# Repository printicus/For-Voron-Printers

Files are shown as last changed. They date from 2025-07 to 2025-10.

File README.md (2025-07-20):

# For Voron Printers
Parts, modded parts and accessories for Voron Printers

These are a ME project. I designet, remixed or modded these files for me, but I uploaded them here, maybe someone will find them interesting and will want to use them. I use Super Slicer as my slicer of choice, wich has an option for "Vertical Hole shrinking compensation" that allows me to tune vertical holes diameter without modifying other dimensions. This will make the vertical holes a bit smaller when my files are used with other slicers, especially for screw holes ment for selftapping. Be aware of that, or parts will break!

I included a file for vertical hole tuning if you want to do that.

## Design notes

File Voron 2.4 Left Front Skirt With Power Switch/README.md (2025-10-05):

# Voron 2.4 Left Front Skirt With Power Switch

Much easier to power on and off the printer. Can be used as a emergency switch. I dont know if it fits a Trident, I did not check.

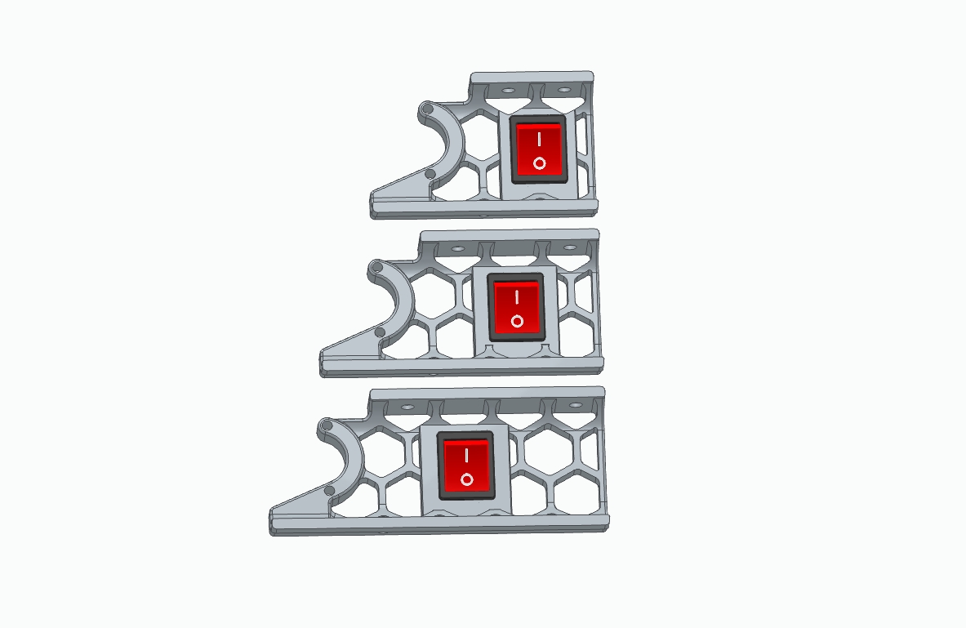
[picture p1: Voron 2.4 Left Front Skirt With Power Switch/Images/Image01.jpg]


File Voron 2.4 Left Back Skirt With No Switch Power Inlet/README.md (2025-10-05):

# Voron 2.4 Left Back Skirt With No Switch Power Inlet

If you have a front power switch on your Voron 2.4, maybe you will need this.

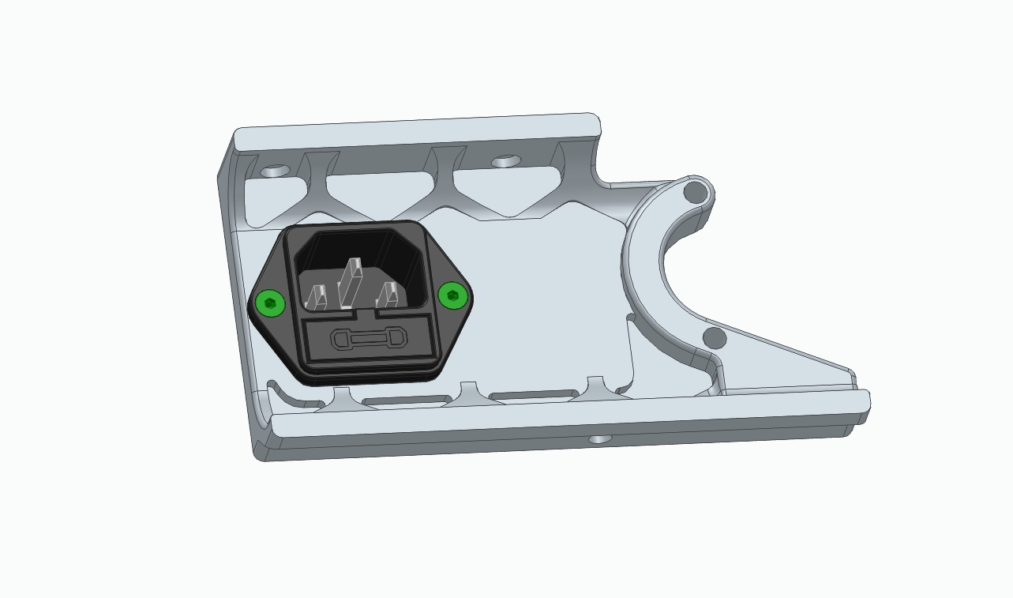
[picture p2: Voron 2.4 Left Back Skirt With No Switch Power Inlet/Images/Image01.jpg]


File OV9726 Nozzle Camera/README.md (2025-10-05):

# Nozzle Camera for Toolchanger XY Nozzle Calibration

Camera setup for XY nozzle calibration in toolchanger setups. Can be use for that with [Axiscope]( https://github.com/nic335/Axiscope ) or any other softare. Or it can be used as a simple webcam on your computer.

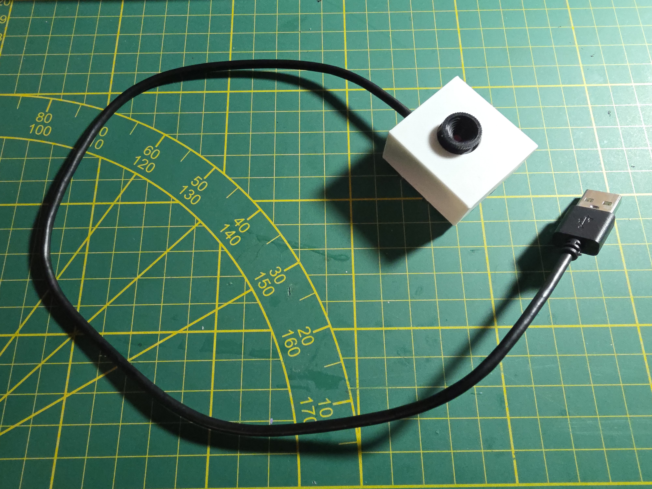
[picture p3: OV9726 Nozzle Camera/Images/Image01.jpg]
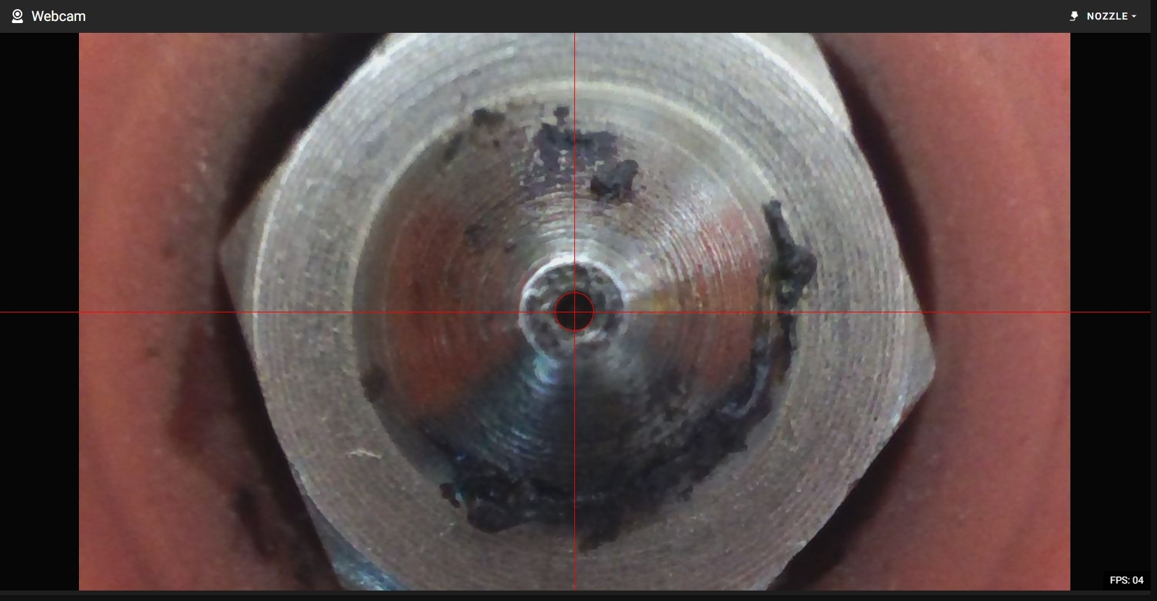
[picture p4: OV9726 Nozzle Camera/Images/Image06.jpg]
  

## BOM:
- Filament whatever type you want
- M3 Heat Insert x4
- M3x10 Socket Head(can be M3x12) x4
- OV9726 Camera Module(or similar) [Aliexpress]( https://www.aliexpress.com/item/1005003808666298.html )
- 6x3x2 N52 Magnets x8
- M2x6 Countersunk Self Tapping Screw x8

Alternative to magnets you can simply use double sided tape.

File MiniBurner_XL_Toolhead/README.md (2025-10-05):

## MiniBurner XL Toolhead

This are the files for Miniburner XL Toolhead.

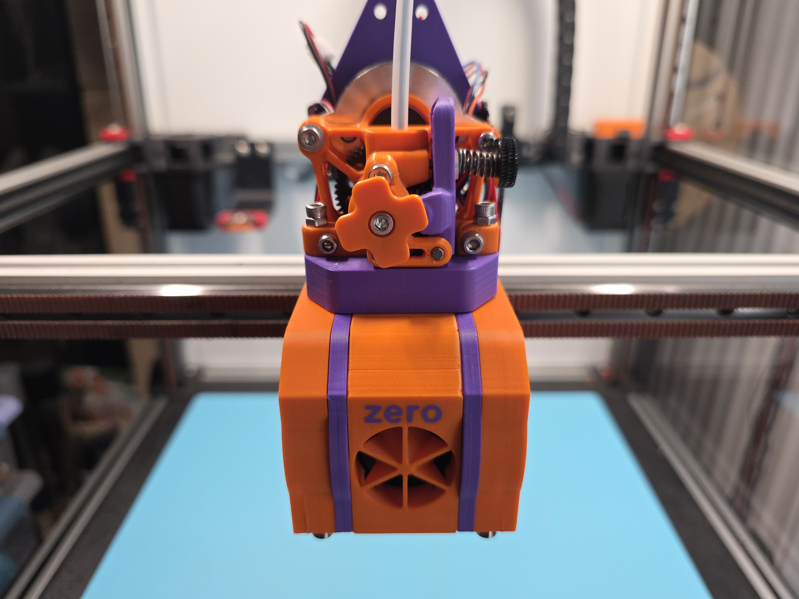
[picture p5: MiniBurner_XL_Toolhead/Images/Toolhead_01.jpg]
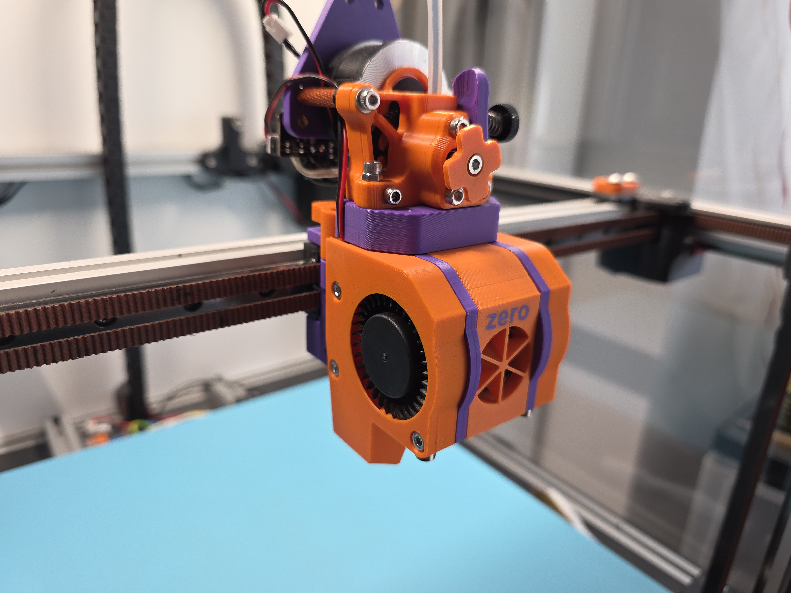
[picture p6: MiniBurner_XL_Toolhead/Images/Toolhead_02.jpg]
  

Its build for hotends with volcano lenght nozzle, has a 2510 hotend cooling fan, and dual 5015 "rehoused" part cooling fans.
For now only 3 hotend are suported, and extruder suport are for sherpa-mini and Orbiter v2 - v2.5.

I designet this toolhead to be compatible with the original Voron X-Carriage, and for [Klicky-Changer](https://github.com/printicus/Klicky-Changer)

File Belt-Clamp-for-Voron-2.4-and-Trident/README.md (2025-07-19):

# Belt Clamp for Voron 2.4 an Trident
 Belt Clamp

Adjustable X-Y Belt Clamp for 6 and 9mm belts, for use with Voron 2.4 and Trident. It can be adjusted so that it will remove the belt tension between the clamps so that you can mount or change the shuttle. It can be used allso for pretensioning new belts.

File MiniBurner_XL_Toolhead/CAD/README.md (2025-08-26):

## MiniBurner XL Toolhead

CAD files for my toolhead Miniburner XL.

An Atempt for an assembly tutorial:

Assembly Tutorial (https://youtu.be/ew-SoRTqHR0)  Fan Prepping (https://youtu.be/SxsvMOHyB7k)

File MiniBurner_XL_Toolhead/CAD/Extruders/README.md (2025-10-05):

## Bom for Extruder Suports:
- Filament: ABS or ASA
- Heat Inserts(voron specs) x2
- M3x20 x2 Cap Screws for securing the extruder support on the toolhead
  - For Sherpa Mini:
    - M3x18  x2 Cap Screws - for securing the extruder on the extruder support
    - M3x25  x2 Cap Screws - for securing the extruder on the extruder support with the filament cutter addon
  - For Orbiter v2
    - M3x14  x2 Cap Screws - for securing the extruder on the extruder support
    - M3x20  x2 Cap Screws - for securing the extruder on the extruder support with the filament cutter addon

## Toolboards Supports

You can use the toolboarts supports that I providet here or you can use whatever toolboards supports you can find online that apply to the Sherpa Mini and Orbiterv2
## BOM:
- Filament: ABS or ASA
- Heat Insert(voron specs) x2
- M3x8  x2 for securing the toolboard support on the extruder
- M3x10  x2 for securing the toolboard
- Spacer  x2 between the extruder and extruder support. the lenght for this spacers depends on what size(length) motors you have. I prefer metalic ones.

## Links:
- Spacers - https://de.aliexpress.com/item/1005006251587333.html - or - https://de.aliexpress.com/item/1005003493226449.html

# Filament Cutter Addon

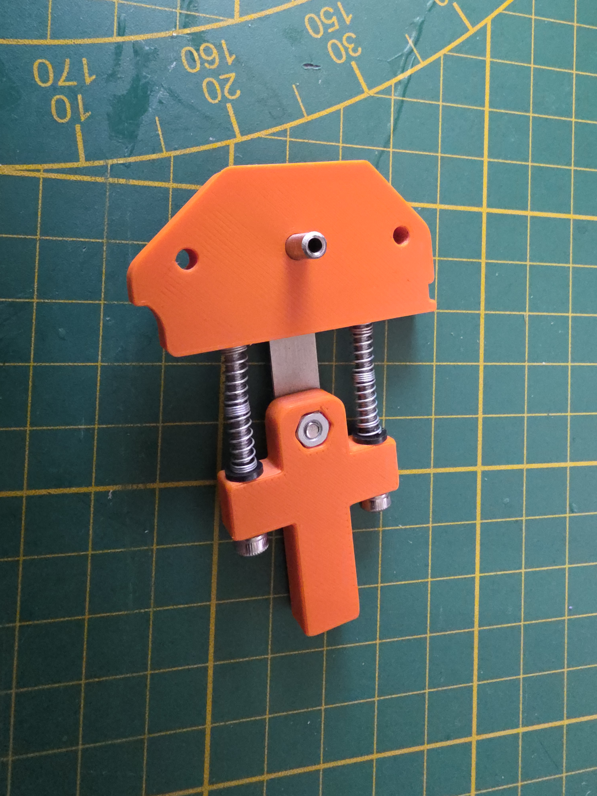
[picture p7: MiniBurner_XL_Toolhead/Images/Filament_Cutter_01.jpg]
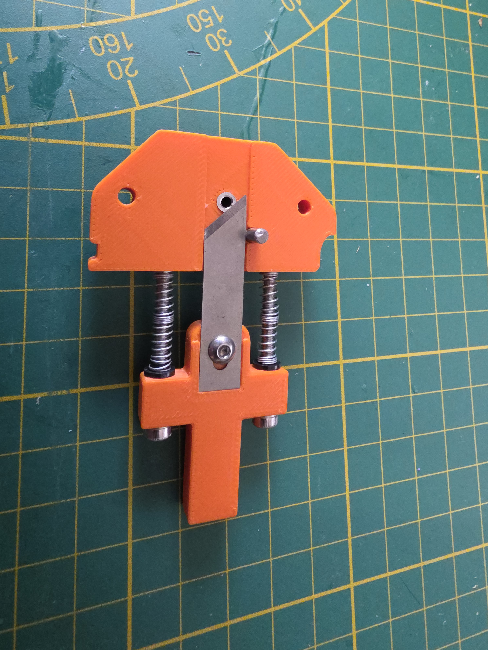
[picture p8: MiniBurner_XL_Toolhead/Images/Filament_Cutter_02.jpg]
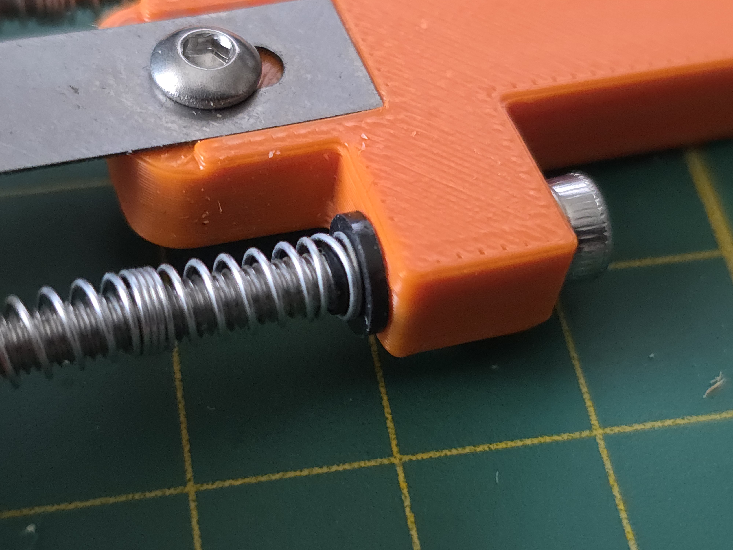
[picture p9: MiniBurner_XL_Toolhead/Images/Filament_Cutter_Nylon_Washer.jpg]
    

The Filament Cutter Addon is ment for use in regular non toolchanger setups, with or without an MMU of some sort. I do not recomend using with a toolchanger setup, the pin interlocking system between the shuttle and backplate is not ment for such shocks.

## BOM for Filament Cutter Adaptor:

- Filament: ABS or ASA
- M3x6 x1
- M3 Nut x1
- M3x35 x2pcs
- 2 springs from a ballpoint pen
- Blade x1
- 4mm OD x 2mm ID  metalic tubing
- 3mmx10mm pin

# Printing:

4 walls, 5 tops and bottoms, 40-50 infill.

# Links:

- Blade - https://www.amazon.de/dp/B0CXCX7GPG?ref=ppx_yo2ov_dt_b_fed_asin_title&th=1
- Metal Tubbing - https://de.aliexpress.com/item/1005005681927768.html
- Nylon washers(optional) - https://de.aliexpress.com/item/33004939470.html

# Assembly:

Guide yourself from the pictures. The M3x35 screws must be with half lenght thread. If you have with full lenght thread you will need to use the nylon washers I linked above, or the spring will get caught on the screw threads and will get pulled in the hole of the blade holder and jam the hole thing. You will need to adjust how much the long screws are screwed in the printed part so that the blade will sit close to the filament. The 3mm pin is used keep the blade straight when cutting. The small piece of metal tubing is necesary so that the blade should have something to cut against. You can use a PTFE tubing for that, but I think the PTFE tubing will crack over time. The tubing should be flush on the blade side and go on the extruder exit port as long as needet. The PTFE tubing from the hotend should end flush on top of the extruder adapter printed part, and should be chamfered to aid the filament entry.

# The Pusher.

The Pusher is a piece of plastic that holds an M5 screw. Its uset to push the Filament Cutter cutting lever(blade holder) against and cut the filament. The M5 screw must be adjusted so that when the toolhead is in position in front of the M5 screw ready to do the cutting, the distance between the M5 screw and the cutting lever should be about 0.5-1mm.

# BOM for Pusher

- Filament: ABS or ASA
- M3x12 x2
- M3 Hammerhead T-Nut x2
- M5x20 Screw

# Printing:

4 walls, 5 tops and bottoms, 40-50 infill.

# Macro:

```
[gcode_macro CUT_FILAMENT_AND_UNLOAD]
description: Cut and Unload filament
gcode:
    M109 S230
    G92 E0                # Zero the extruder
    G1 E-30 F1000
    FILAMENT_CUT
    G90
    G1 X175 Y50 Z100 F8000
    G92 E0                # Zero the extruder
    G1 E-100 F500
    G92 E0                # Zero the extruder
#    M104 S0               # Turn-off hotend

[gcode_macro FILAMENT_CUT]
description: Cut The Filament
# you must set the x pos in front of the pusher
# the distance between the pusher and the cutting lever(blade holder) should be arround 0.5-1mm when toolhead is in position in front of the pusher befor cutting. adjust the Pusher M5 screw accordingly
gcode:
    G90
    G1 X271 Y{printer.configfile.settings.stepper_y.position_max-4} F15000    # move toolhead in position befor cutting
    G1 Y{printer.configfile.settings.stepper_y.position_max}                  # cut
    G1 Y{printer.configfile.settings.stepper_y.position_max-10} F15000        # move away
```

The FILAMENT_CUT macro does only the cut move. The CUT_FILAMENT_AND_UNLOAD macro will heat up the nozzle, retract a small amount of filament, activate the FILAMENT_CUT macro and move the toolhead in the front of the printer, then unload the rest of the filament. Feel free to modify those macro at will.

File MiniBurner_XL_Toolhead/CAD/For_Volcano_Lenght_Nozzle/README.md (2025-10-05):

# Miniburner XL toolhead.

The Miniburner XL Toolhead is ment for mounting on a Voron2.4 or Voron Trident printer. For that it can be mounted on the original voron carriage. This comes with some dimensions constraints on X an Y, so it will reach the entire build plate. [For that the 5015 partcooling fans need to be "rehaused"](https://youtu.be/SxsvMOHyB7k). That means that they will need to be disassembled and modified by cutting. The only parts used will be the blades and the backplate on what the fan is actual mounted, cut to a proper diameter for mounting on the "fan_support" printed part.

The GDSTIME fans backplate need to be cut at max 39mm diameter, Sunon at max 37mm.

Example:

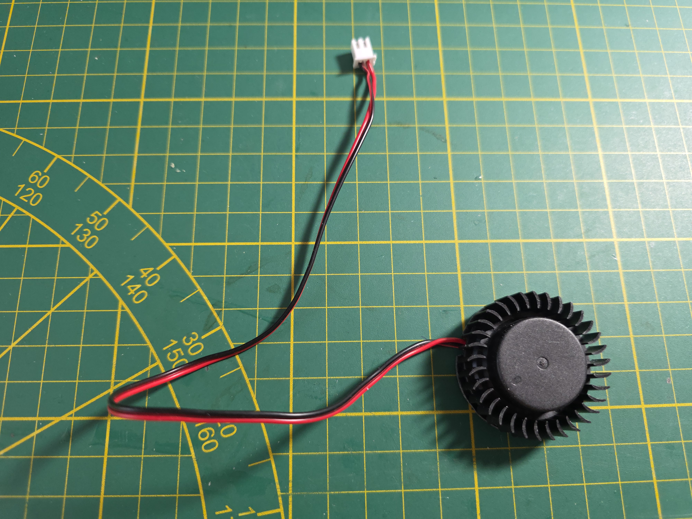
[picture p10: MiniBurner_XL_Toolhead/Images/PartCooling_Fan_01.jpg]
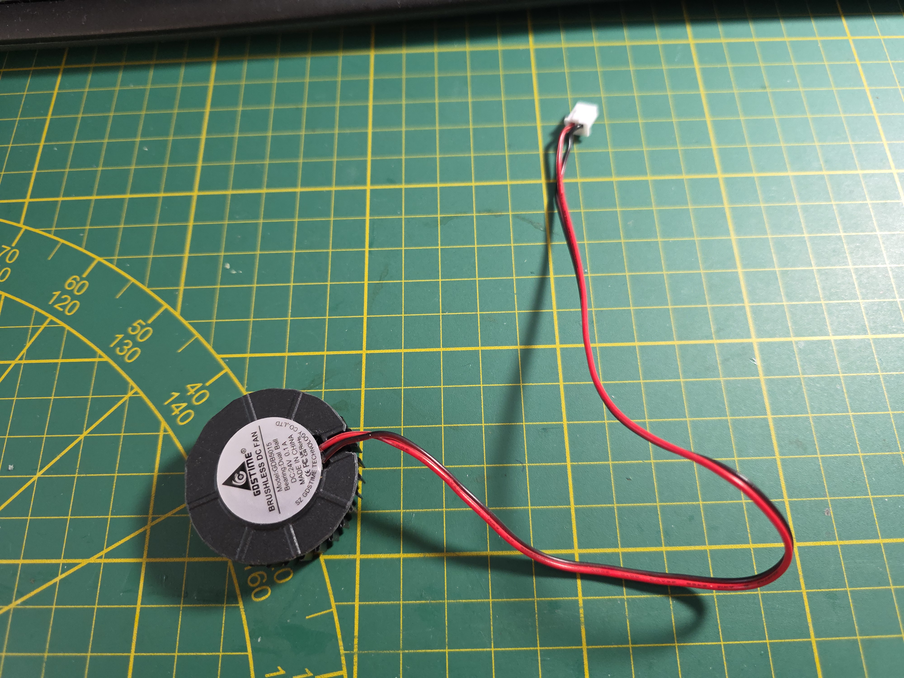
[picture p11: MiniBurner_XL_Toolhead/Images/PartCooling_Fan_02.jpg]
  

The partcooling fan parts and front cover are the same for all toolheads in this folder. The difference for each hotend supported is the main body.

[Custom Hotend](../For_Volcano_Lenght_Nozzle/Custom_Hotend.md)

## BOM:
- Filament: ABS or ASA
- Color: only pink allowed.... :D
- M2.5x8 x4pcs  screws for hotend
- M3x14  x8pcs  screws, 4pcs for hotend fan, 4pcs for the PCF in the back
- M3x20  x2pcs  screw for the PCF in the front
- LED's
- 2510 axial fan x1
- 5015 radial fan x2 - I designed rehausing printed parts only for GDSTIME and Sunon fans.

## If mounted on the voron x-carriage:
- M3x10  x2pcs screw
- M3x10  x2pcs countersunk screw

## If used in an toolchanger setup:
- M3x8   x4pcs countersunk screw for mounting on the backplate
- 6x3x2  x4pcs magnets
- M2x8   x4pcs countersunk selftapping screws for the magnets

## Links:
- Magnets:  https://www.buyneomagnets.com/p/6mm-dia-x-3mm-thick-with-countersunk-hole-2mm-n35-strong-countersunk-neodymium-disc-magnets-countersunk-ring-rare-earth-magnet
- Screws for magnets: https://vi.aliexpress.com/item/1005006676743568.html
- Leds:  https://de.aliexpress.com/item/1005005515068181.html

  or - https://de.aliexpress.com/item/1005006223955083.html - these are the RGB variant. Need to be connected to an RGB port on the toolboard.

##Printing:
- 4 walls, 5 tops and bottoms, 40-50% infill.
- Supports: maybe, depends on your slicer settings. The main body parts and the part cooling fan covers could need some suports.

Example paint-on supports:

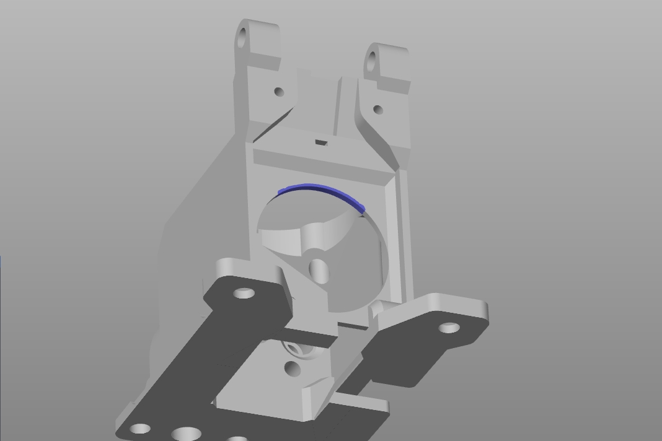
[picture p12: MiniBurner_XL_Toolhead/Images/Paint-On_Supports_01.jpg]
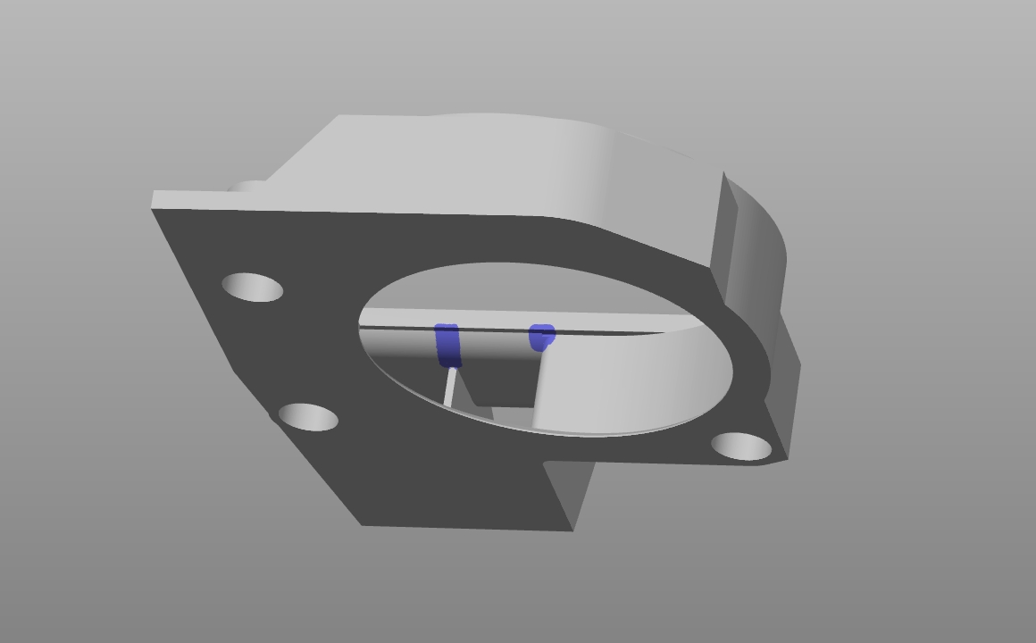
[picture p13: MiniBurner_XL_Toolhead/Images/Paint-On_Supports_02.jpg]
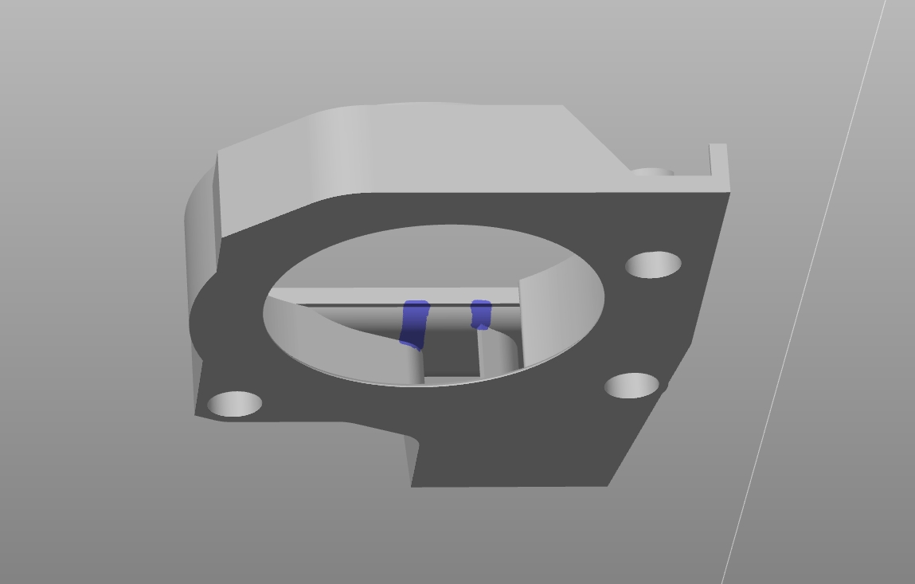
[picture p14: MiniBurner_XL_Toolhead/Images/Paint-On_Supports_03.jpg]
    

## All stl's are positioned in the correct position for printing.

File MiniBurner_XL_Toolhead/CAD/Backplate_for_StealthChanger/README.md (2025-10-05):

# Backplate fur using Miniburner XL Toolhead with StealthChanger toolchanger.

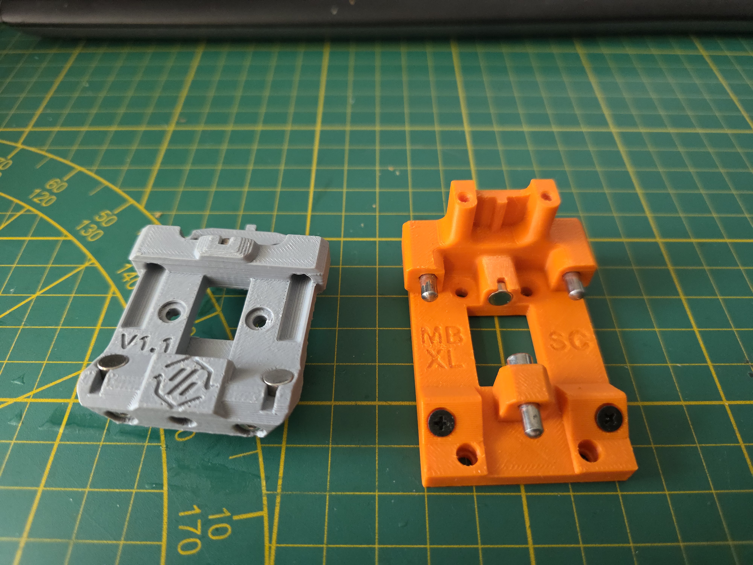
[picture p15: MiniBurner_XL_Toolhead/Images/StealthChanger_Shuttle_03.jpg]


Not tested on actual printer, but I printed one Stealtchanger shuttle and it fits nice.

## BOM:
- Filament: ABS or ASA
- M3x4x12  x3 Pins
- M3x8 x1  Cap Screw
- M3x10 x2  Cap Screw
- M3x8 x2  ButtonHead Screw
- M3x6 x2  Countersunk Magnetic Screw
- 6x3 N52 Magnet x1
- Heat Insert(voron specs) x2
- TAP Sensor PCB x1

## Links:
- Pins - https://de.aliexpress.com/item/1005007596796680.html

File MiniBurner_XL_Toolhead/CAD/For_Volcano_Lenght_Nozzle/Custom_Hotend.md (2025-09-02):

The "Main Body for Volcano Heatblock - 21mm heatsink" part uses a custom hotend made from:

The heatsink and heatbreack from [HERE](https://de.aliexpress.com/item/1005006240697835.html) (first and third product)

and can be used with one of these heatblocks: 
- [Trianglelab CHC Pro](https://de.aliexpress.com/item/1005004224332574.html)
- [Trianglelab CHCB-V](https://de.aliexpress.com/item/1005009094131015.html)
- or just a simple volcano heatblock.

The Trianglelab CHCB-V with his original heatsink and heatbreak is not compatible with "Main Body for Volcano Heatblock - 21mm heatsink", because the owerall lenght is shorter and the heatsink is bigger in diameter. For this the part its called "Main Body for Trianglelab CHCB-V".

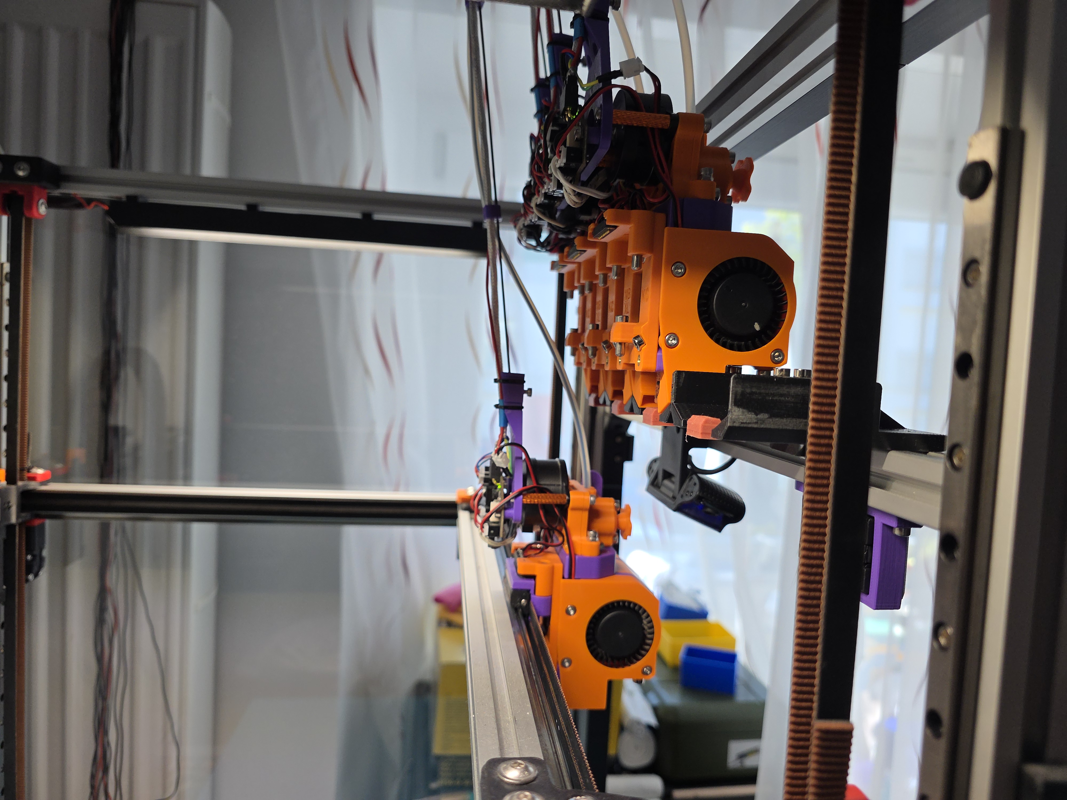
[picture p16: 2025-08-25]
MiniBurner_XL_Toolhead/Images/Umbilical_03.jpg

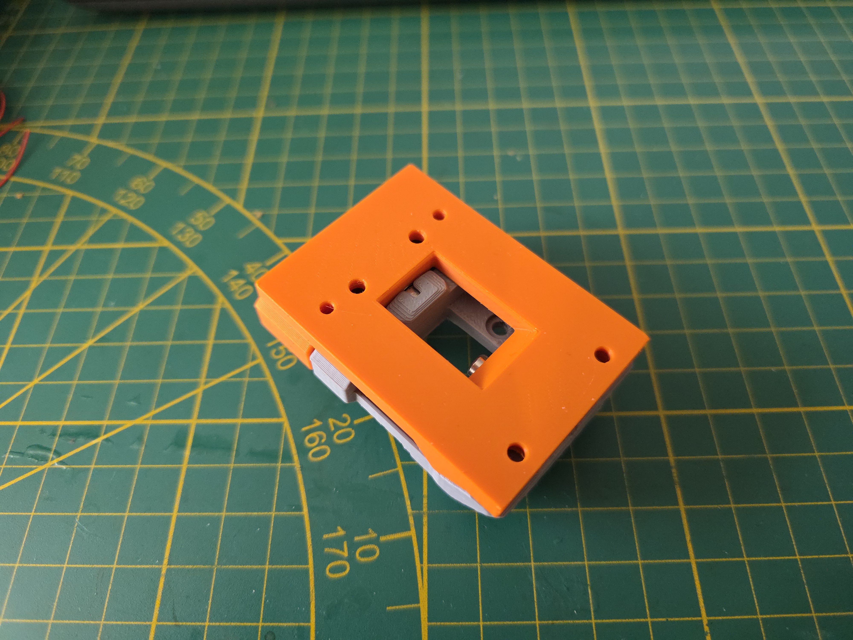
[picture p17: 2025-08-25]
MiniBurner_XL_Toolhead/Images/StealthChanger_Shuttle_01.jpg

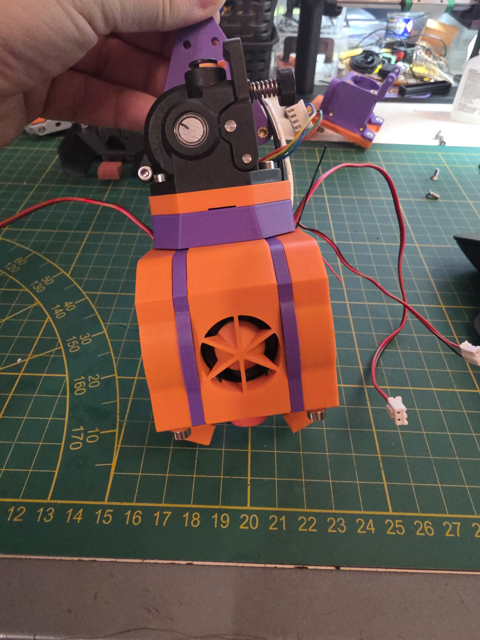
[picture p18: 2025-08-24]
MiniBurner_XL_Toolhead/Images/Toolhead_07.jpg

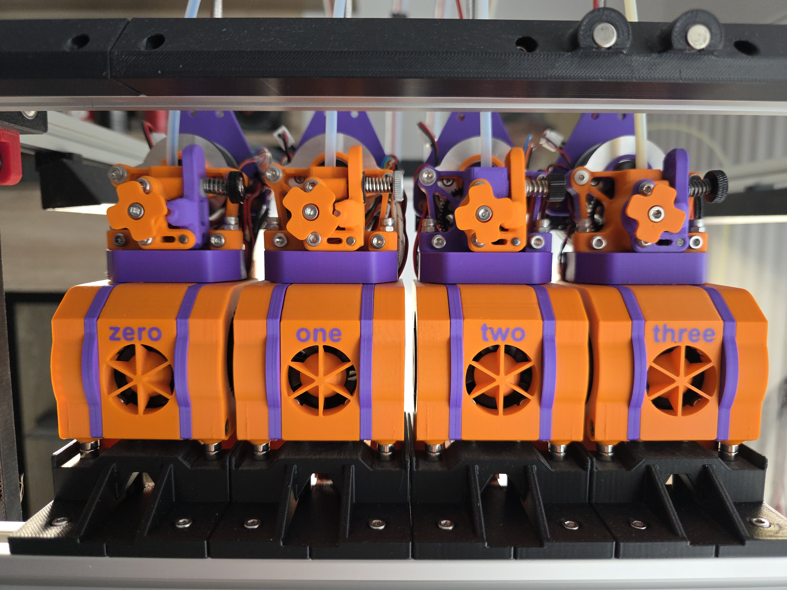
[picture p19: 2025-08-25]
MiniBurner_XL_Toolhead/Images/Toolhead_04.jpg

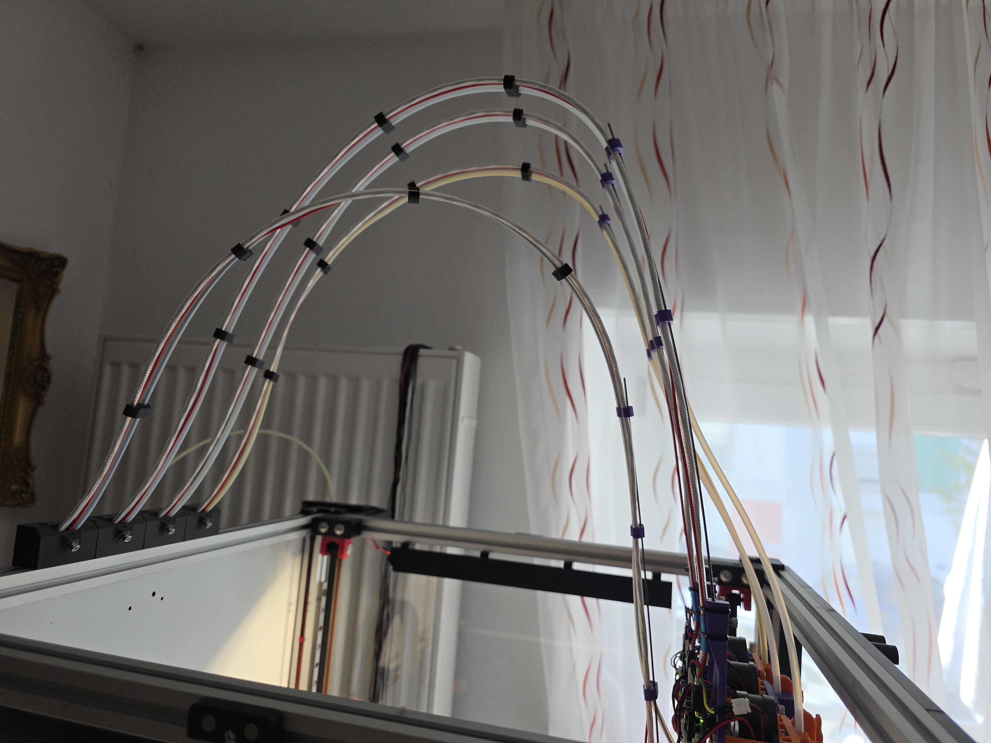
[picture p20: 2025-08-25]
MiniBurner_XL_Toolhead/Images/Umbilical_02.jpg

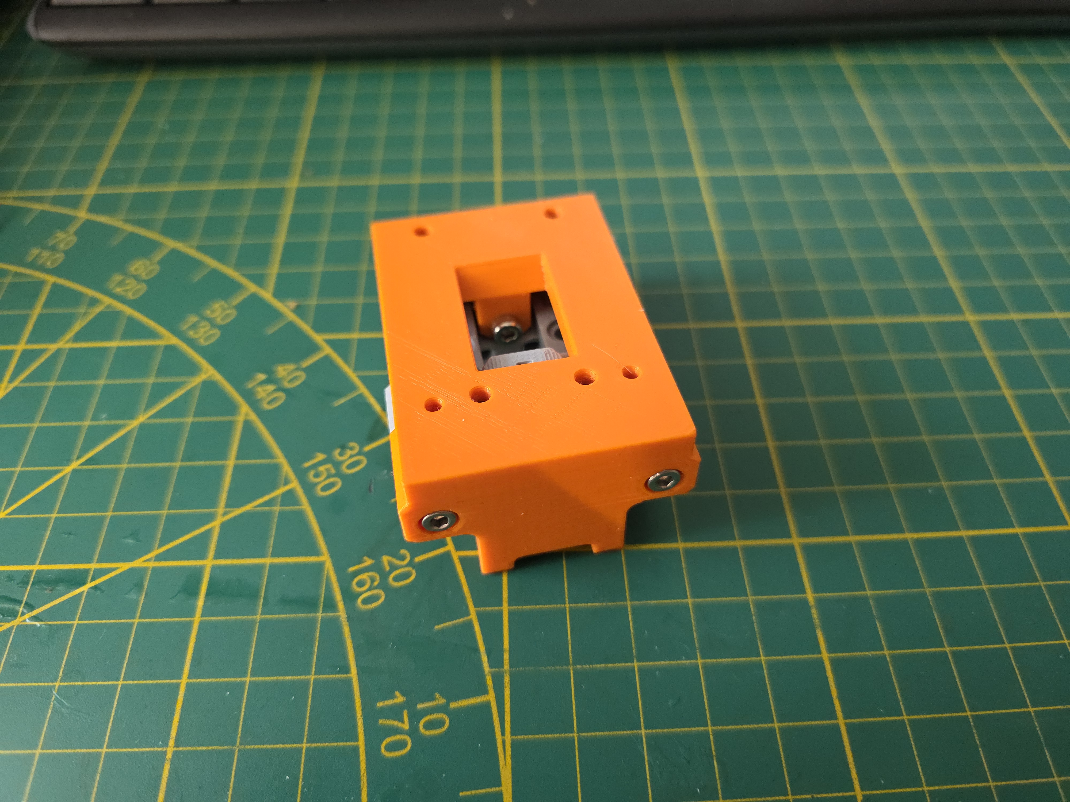
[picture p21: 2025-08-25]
MiniBurner_XL_Toolhead/Images/StealthChanger_Shuttle_02.jpg

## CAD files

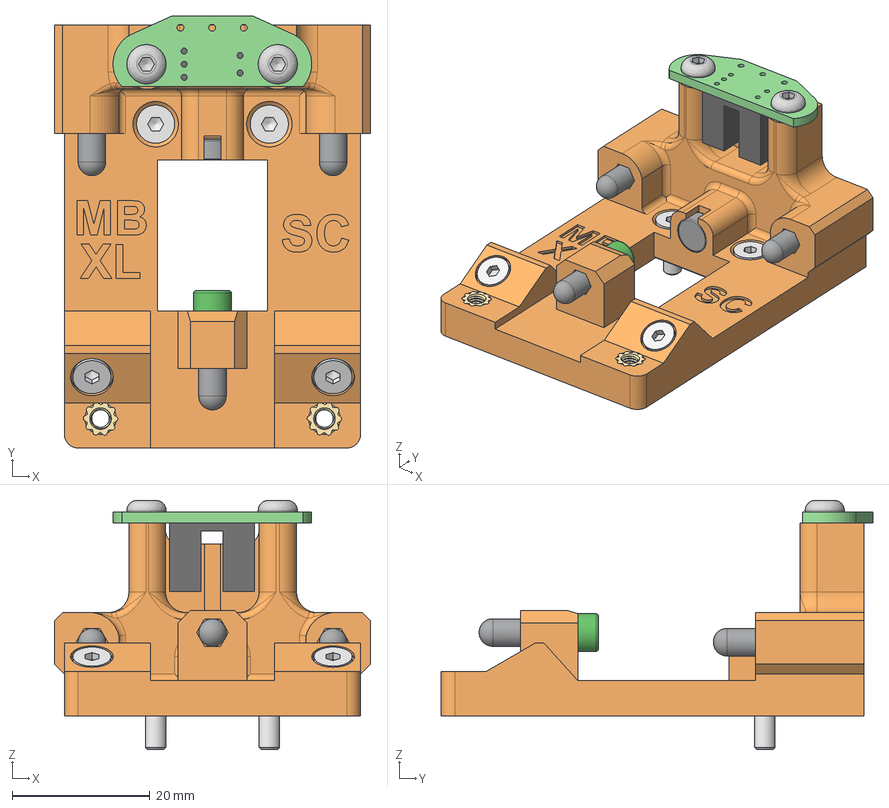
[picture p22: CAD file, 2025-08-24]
MiniBurner_XL_Toolhead/CAD/Backplate_for_StealthChanger/MiniBurner_XL_-_StealthChanger_Backplate_-_Assembly.step
45.9 x 62.7 x 36.2 mm
MiniBurner XL - StealthChanger Backplate
M3x6 FHCS x 2
Board
Sensor
M3x6 BHCS x 2
4x12mm Pin x 3
M3x10 hex socket cap screw x 2
M3x8 hex socket cap screw
M3x10 FHCS x 2
6x3 Magnet
Heat Insert M3 Short 5x4 x 2

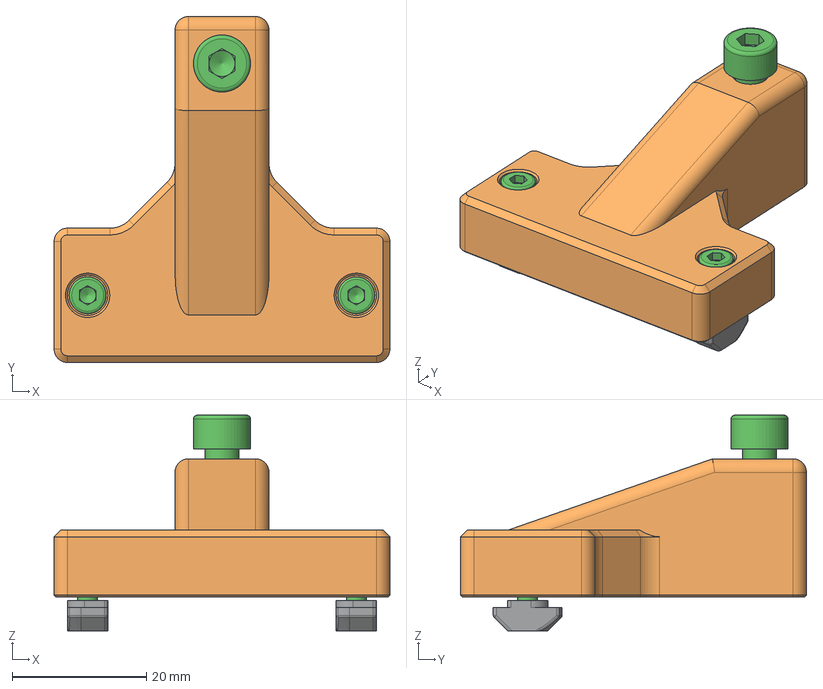
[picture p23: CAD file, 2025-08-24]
MiniBurner_XL_Toolhead/CAD/Extruders/Pusher_for_Filament_Cutter_Assembly.step
50.0 x 51.5 x 32.1 mm
Pusher for Filament Cutter
M5x20 hex socket cap screw
M3x12 hex socket cap screw x 2
M3 Hammerhead T-Nut x 2

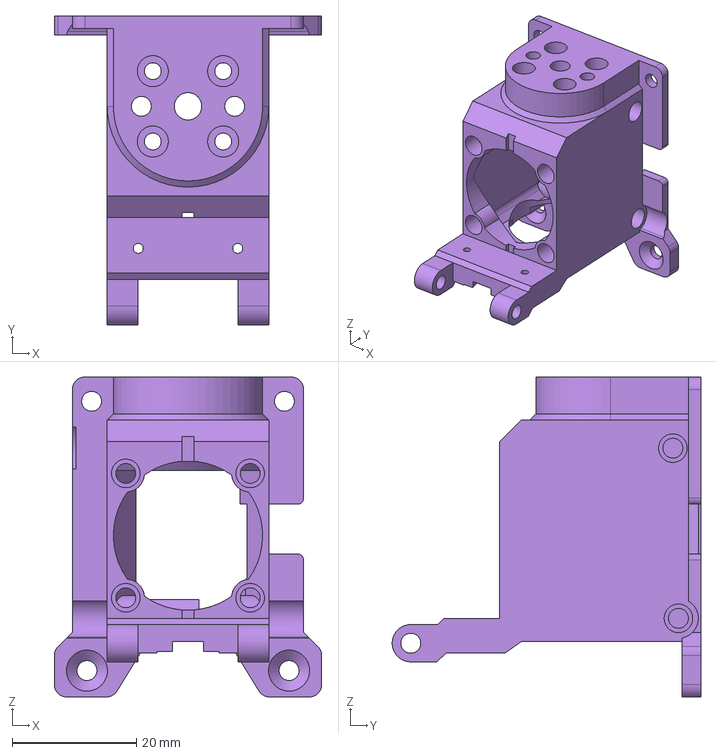
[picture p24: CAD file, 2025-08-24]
MiniBurner_XL_Toolhead/CAD/For_Volcano_Lenght_Nozzle/Main_Body_for_Trianglelab_CHCB-V.step
43.0 x 49.6 x 51.5 mm

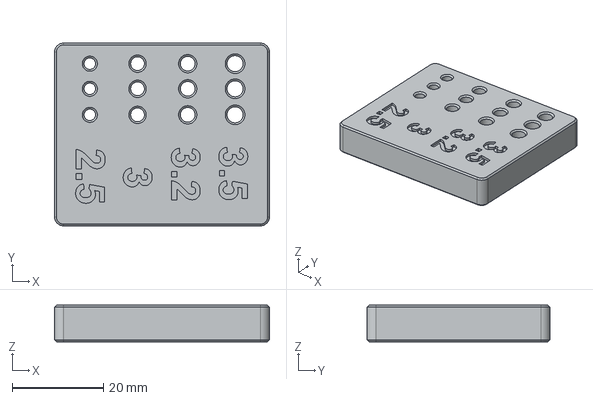
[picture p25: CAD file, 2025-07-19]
@-Vertical-Hole-Calibration/Hole Calibration.step
47.0 x 40.0 x 8.00 mm

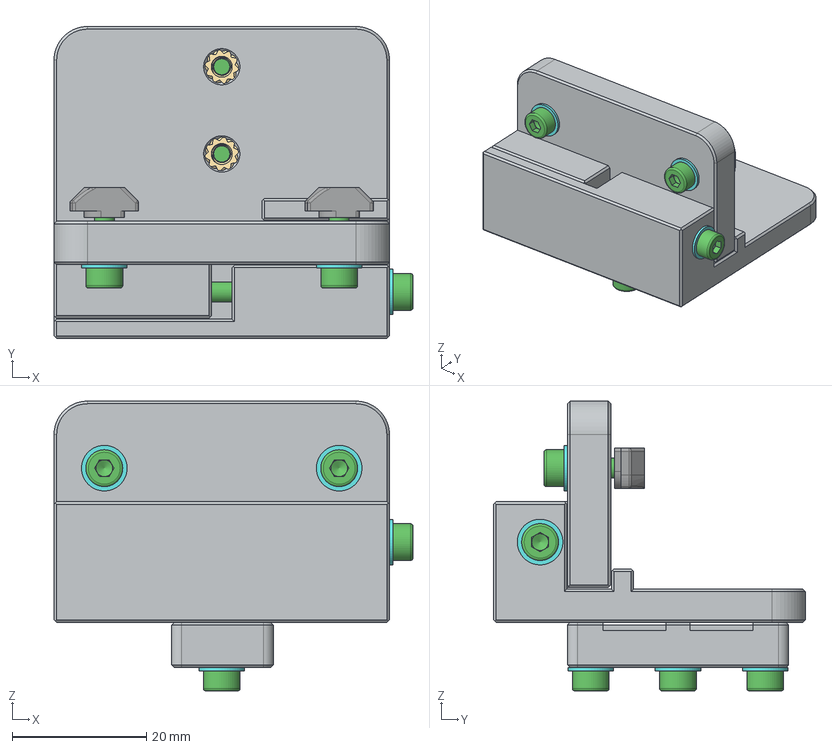
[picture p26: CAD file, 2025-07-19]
Belt-Clamp-for-Voron-2.4-and-Trident/CAD/Right Side.step
53.5 x 46.5 x 43.2 mm
XY belt clamp - right - part a
XY belt clamp - right - part b
XY belt clamp - common
Heat Insert M3 Short 5x4 x 4
M3 Washer x 6
M3x12 hex socket cap screw x 5
M3x50 hex socket cap screw
M3 Hammerhead T-Nut x 2

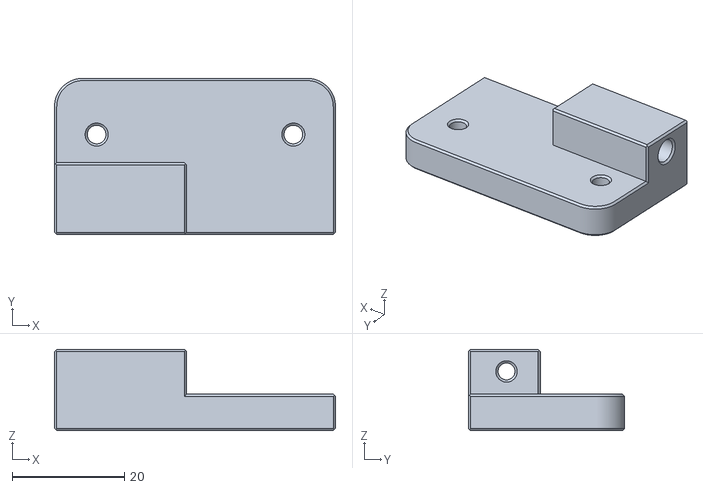
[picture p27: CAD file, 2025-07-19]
Belt-Clamp-for-Voron-2.4-and-Trident/STL/XY belt clamp - right - part b.stl
50.0 x 27.8 x 14.5

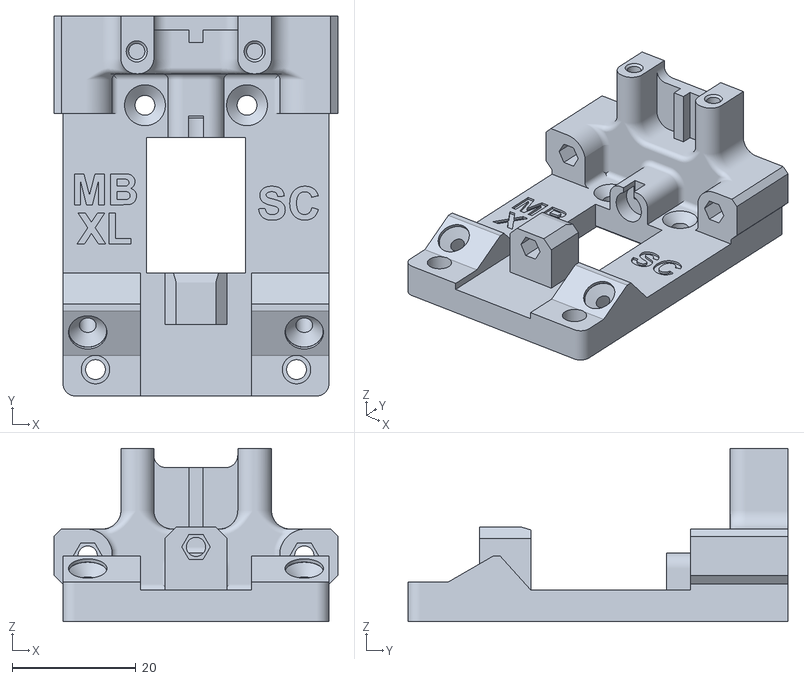
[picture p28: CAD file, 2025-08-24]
MiniBurner_XL_Toolhead/STL/Backplate_for_StealthChanger/MiniBurner_XL_-_StealthChanger_Backplate.stl
45.9 x 61.4 x 28.0

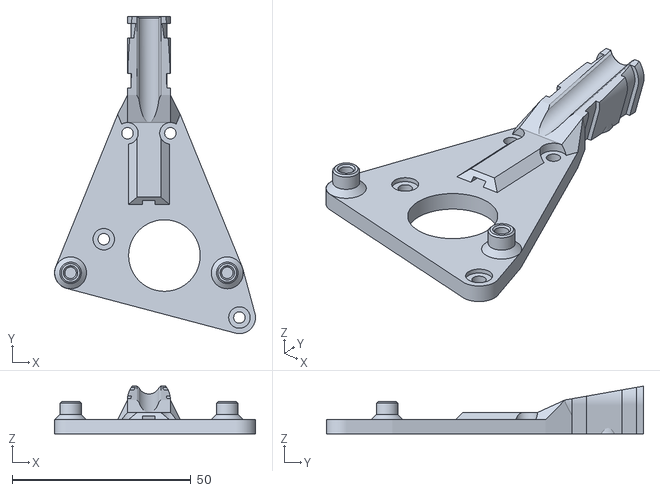
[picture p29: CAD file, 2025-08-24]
MiniBurner_XL_Toolhead/STL/Extruders/For_Orbiter_v2/Orbiter_v2_CAN_PCB_Umbilical_Mount_for_3x0.3_flat_spring-steel.stl
56.2 x 88.7 x 13.4

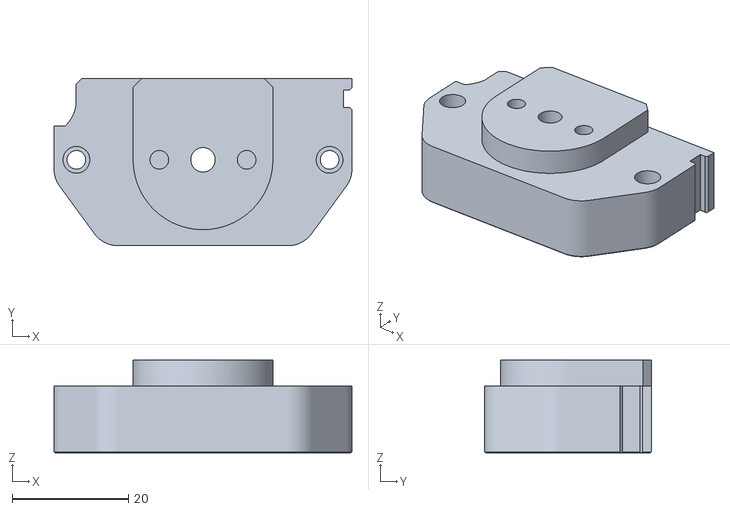
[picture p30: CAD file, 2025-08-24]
MiniBurner_XL_Toolhead/STL/Extruders/For_Sherpa-Mini/Sherpa_Mini_Support.stl
51.2 x 28.7 x 16.0

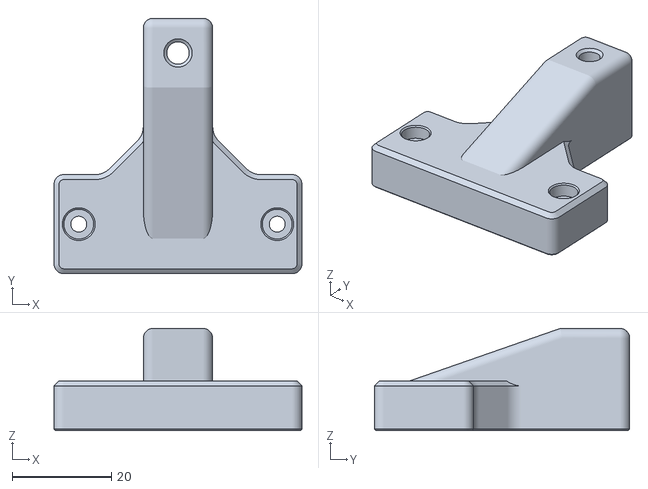
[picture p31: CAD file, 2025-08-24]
MiniBurner_XL_Toolhead/STL/Extruders/Pusher_for_Filament_Cutter.stl
50.0 x 51.5 x 20.6

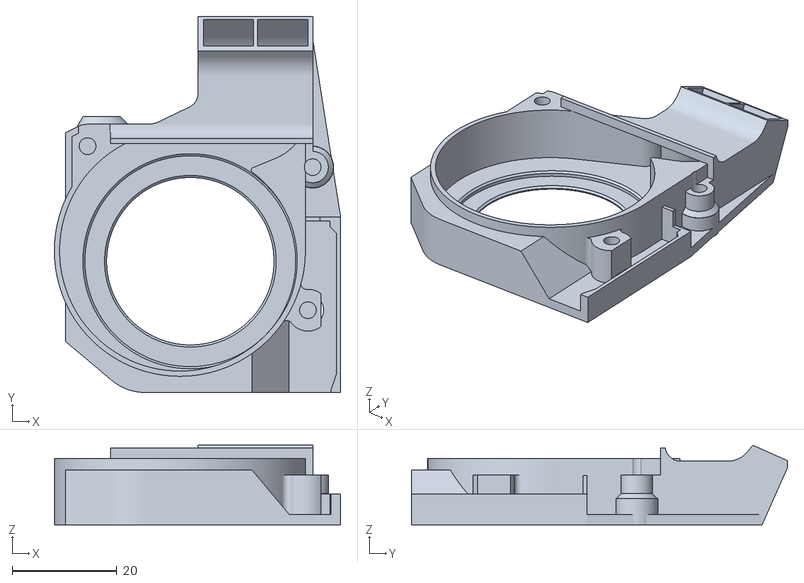
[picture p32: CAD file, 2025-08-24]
MiniBurner_XL_Toolhead/STL/For_Volcano_Lenght_Nozzle/Right_Fan_Cover_-_Sunon.stl
54.7 x 71.9 x 15.2

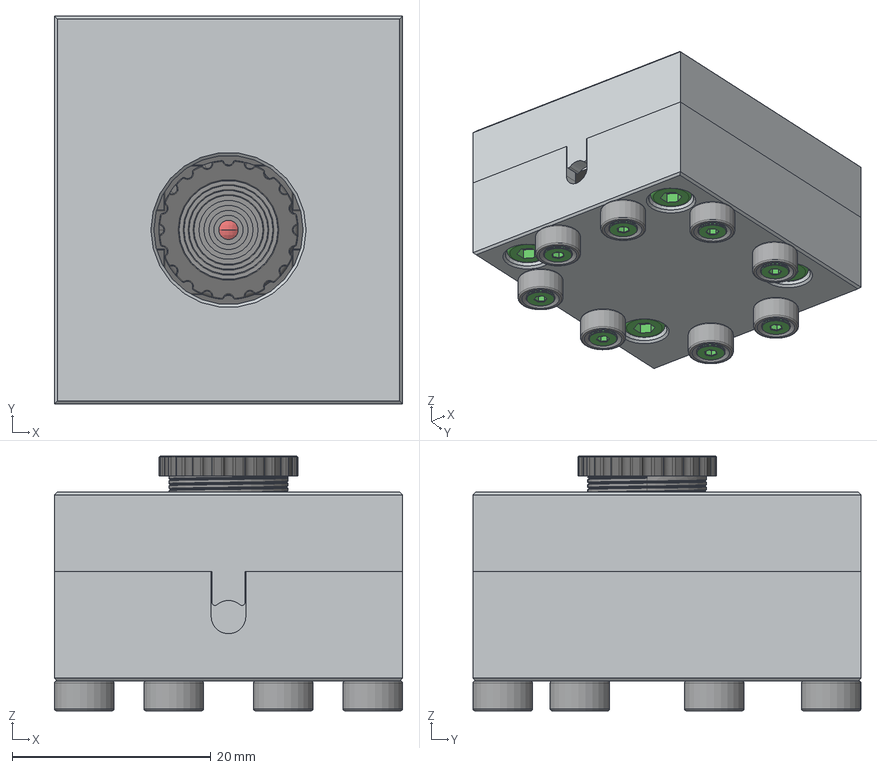
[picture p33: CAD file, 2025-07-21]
OV9726 Nozzle Camera/CAD/OV9726 Nozzle Camera.step
35.0 x 39.0 x 25.6 mm
Top
Heat Insert M3 Short 5x4 x 4
Copy of OV9726 Camera module^OV9726 Camera module
Copy of SOT 23^OV9726 Camera module x 3
Copy of 0402c_2320560^OV9726 Camera module x 28
Copy of QFN36 6x6^OV9726 Camera module
Copy of TSOP-6^OV9726 Camera module
Copy of tsop8^OV9726 Camera module
Copy of sm04b-srss-tb_lf__sn_^OV9726 Camera module
cross fh tapping 7976_din_Tapping screw DIN 7982-ST2.2x4.5-C-H-N x 2
Bottom
M3x10 hex socket cap screw x 4
6x3 Magnet With 2mm Coutersunk Hole x 8
M2x6mm - Screw Countersunk x 8

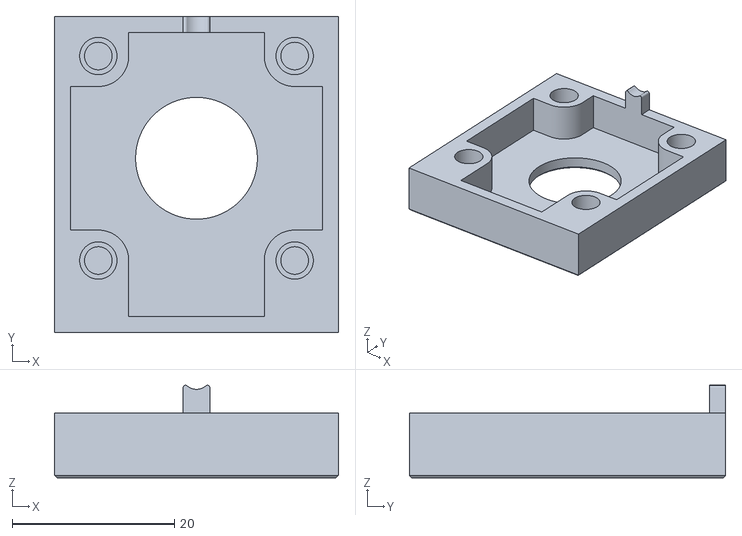
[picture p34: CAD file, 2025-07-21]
OV9726 Nozzle Camera/STL/Top.stl
35.0 x 39.0 x 11.4

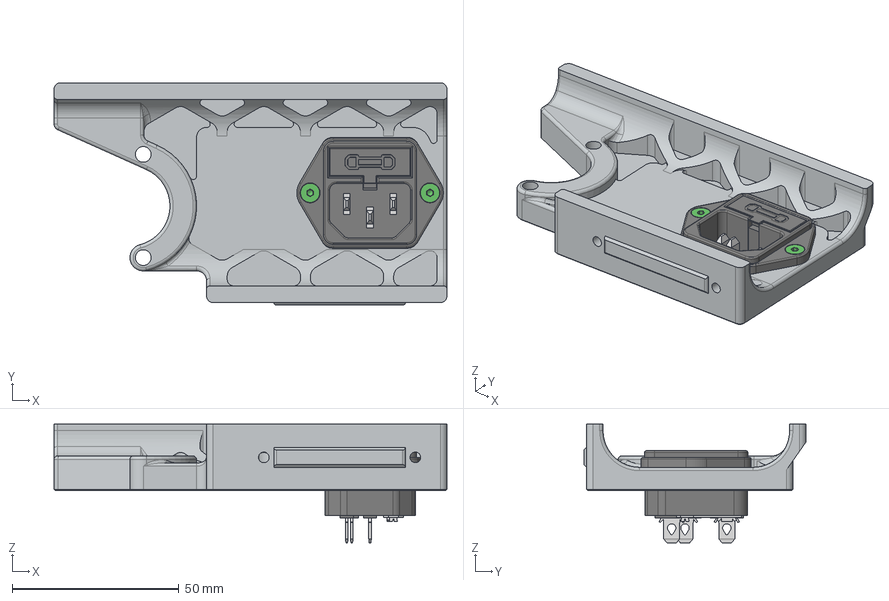
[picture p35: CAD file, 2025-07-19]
Voron 2.4 Left Back Skirt With No Switch Power Inlet/CAD/power_inlet_no_power_switch.step
118.0 x 66.8 x 35.7 mm
power_inlet_no_power_switch
Main Plug JR-101-1F
Heat Insert M3 Short 5x4 x 2
M3x10 hex countersunk-head screw x 2

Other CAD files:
MiniBurner_XL_Toolhead/CAD/For_Volcano_Lenght_Nozzle/Main_Body_for_Rapido_HF.step
MiniBurner_XL_Toolhead/STL/For_Volcano_Lenght_Nozzle/Main_Body_for_Volcano_Heatblock_-_21mm_heatsink.stl
Voron 2.4 Left Front Skirt With Power Switch/CAD/front_skirt_a_350_with_power_switch-Body.step
Belt-Clamp-for-Voron-2.4-and-Trident/CAD/Left Side.step
@-Vertical-Hole-Calibration/Hole Calibration.stl
Belt-Clamp-for-Voron-2.4-and-Trident/STL/XY belt clamp - common - x2.stl
Belt-Clamp-for-Voron-2.4-and-Trident/STL/XY belt clamp - left.stl
Belt-Clamp-for-Voron-2.4-and-Trident/STL/XY belt clamp - right - part a.stl
MiniBurner_XL_Toolhead/CAD/Extruders/Orbiter_v2_CAN_PCB_Umbilical_Mount_for_3x0.3_flat_spring-steel.step
MiniBurner_XL_Toolhead/CAD/Extruders/Sherpa_Mini_CAN_PCB_Umbilical_Mount_for_3x0.3_flat_spring-steel.step
MiniBurner_XL_Toolhead/STL/Extruders/For_Orbiter_v2/Blade_Holder_-_M3_Nut.stl
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

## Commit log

2025-07-19 New Stuff
    [XY belt clamp - right - part a.stl]
2025-08-24 Update and rename Custom Hotend to Custom Hotend.md
2025-08-24 Update Custom Hotend.md
